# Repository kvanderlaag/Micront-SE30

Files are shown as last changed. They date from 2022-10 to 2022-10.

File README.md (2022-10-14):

# Micron't SE30 Beigescale Adapter
 
Micron XCEED CRT yoke board for internal greyscale on the Macintosh SE/30

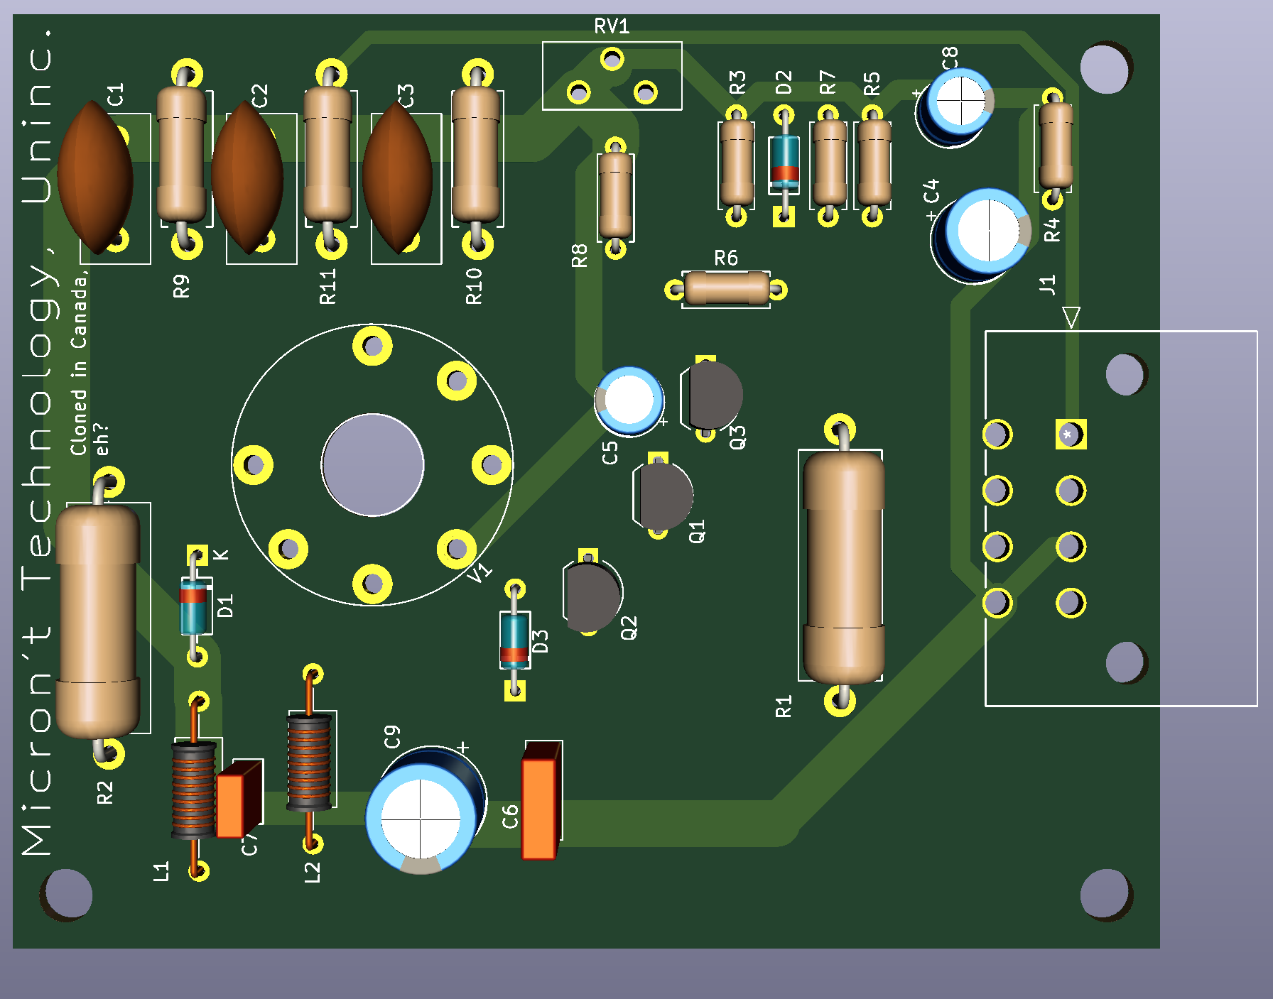
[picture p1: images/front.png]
Board front rendering

 
If you've miraculously stumbled across one (or two) of the assorted Micron SE/30 PDS video cards which have the connector for internal greyscale output, the piece you may be missing is the board which slaps onto the back of the CRT to let it run greyscale rather than black and white. (Also the associated adapter harness.)
 
As far as I know, these have been cloned many times, and sold by various parties. All of these clones are largely derived from [Gamba's original work to this end](http://web.archive.org/web/20010626004329/http://www.accesscom.com/~gamba/microngray.html), which is no longer actively available, but by the mercy of the [internet gods](https://www.archive.org) still archived. This board doesn't provide anything that the others don't -- it's also just a straight clone, though the routing and component placement is a little more closely derived from [D.S. Larsen's photos of the original Micron board.](http://web.archive.org/web/20010626004329/http://www.eskimo.com/~dslarsen/micron/)
 
The two important things about this design are:
1. That it was created on 14-10-2022, using footprints for parts that are actively available at this time, and
2. _That it actually fuckin' exists on GitHub, with an open license._ 
 
Take it, build it, fix it, improve it, use it to make a death ray; I don't care, just _actually do something with it_, because finding someone who will actually sell you one of these today is _annoyingly difficult_.
 
## Known Issues

There is currently one _massive_ caveat: I haven't actually built one of these yet. Everything appears to be lined up to the original board fairly accurately, and I'm confident in the routing relative to the original board and the schematic, but the one thing that concerns me is the footprint for the tube socket. The footprint was created with [this 7-pin miniature (B7G) tube socket, P/N B7G-PCB](http://www.pacifictv.ca/socket.htm) in mind, since the dimensions are provided, but I've also ordered a couple of tube sockets from Aliexpress; if those don't quite fit, I'll create a second version of the board with an updated footprint, just so that there's options for tube socket sourcing, since that seems like it could be a pain in the ass.

Also, obviously, since I haven't built it yet, there's no guarantee it won't blow up your SE/30, or your video card. Since both of these are quite expensive, maybe double check it against Gamba's (known-working) source material before you go build it. I'm not infallible -- in fact, I'm not even that smart -- but I'm also not your dad, so do what you want.

I still need to create a KiCAD schematic of the adapter harness, too.

## Bill of Materials

If you want to actually build this, you probably need some parts to do so. These are the parts the board was designed for; other parts with similar size, lead spacing, and characteristics will probably work fine.

| Quantity | Reference | Part Number | Description | Link | Alternate |
| --- | --- | --- | --- | --- | --- |
| 3 | C1,2,3 | CK45-E3AD103ZYVNA | Capacitor, ceramic disc, 0.01uF 1KVDC | https://www.mouser.ca/ProductDetail/810-CK45-E3AD103ZYVN | |
| 1 | C4 | ESS106M050AE2AA | Capacitor, electrolytic, 10uF, 50VDC, 105°C | https://www.mouser.ca/ProductDetail/80-ESS106M050AE2AA | |
| 1 | C5 | UVZ1A470MDD | Capacitor, electrolytic, 47uF, 10VDC, 105°C | https://www.mouser.ca/ProductDetail/647-UVZ1A470MDD | |
| 1 | C6 | R82EC3100DQ70J | Capacitor, film, 0.1uF, 100VDC | https://www.mouser.ca/ProductDetail/80-R82EC3100DQ70J | |
| 1 | C7 | K104Z15Y5VE5TL2 | Capacitor, multi-layered ceramic, 0.1uF, 25VDC | https://www.mouser.ca/ProductDetail/594-K104Z15Y5VE5TL2 | |
| 1 | C8 | UVZ1C101MDD | Capacitor, electrolytic, 100uF, 16VDC, 105°C | https://www.mouser.ca/ProductDetail/647-UVZ1C101MDD | |
| 1 | C9 | UPW1J101MPD6 | Capacitor, electrolytic, 100uF, 63VDC, 105°C | https://www.mouser.ca/ProductDetail/647-UPW1J101MPD6 | |
| 3 | D1,2,3 | 1N914BTR | Diode, 1N914A | https://www.mouser.ca/ProductDetail/512-1N914BTR | |
| 1 | J1 | 39-29-1088 | Connector, 8 pin, right-angle; Molex 5569 series | https://www.mouser.ca/ProductDetail/538-39-29-1088 | |
| 2 | L1,2 | 78F270J-RC | Inductor, 27 uH 5% | https://www.mouser.ca/ProductDetail/542-78F270-RC | |
| 2 | Q1,2 | 2N5550TFR | Transistor, NPN | https://www.mouser.ca/ProductDetail/512-2N5550TFR | |
| 1 | Q3 | PN2222ABU | Transistor, NPN | https://www.mouser.ca/ProductDetail/512-PN2222ABU | |
| 2 | R1,2 | CFR200JT-73-1K | Resistor, 1.0K ohms, 2W 5% | https://www.mouser.ca/ProductDetail/YAGEO/CFR200JT-73-1K | |
| 1 | R3 | CFR-25JB-52-75R | Resistor, 75 ohms, 1/4W 5% | https://www.mouser.ca/ProductDetail/YAGEO/CFR-25JB-52-75R  | |
| 1 | R4 | CFR-25JR-52-300R | Resistor,  300 ohms, 1/4W 5% | https://www.mouser.ca/ProductDetail/YAGEO/CFR-25JR-52-300R | |
| 1 | R5 | CFR-25JT-52-56R | Resistor, 56 ohms, 1/4W 5% | https://www.mouser.ca/ProductDetail/YAGEO/CFR-25JT-52-56R  | |
| 1 | R6 | CFR-25JT-52-200R | Resistor,  200 ohms, 1/4W 5% | https://www.mouser.ca/ProductDetail/YAGEO/CFR-25JT-52-200R | |
| 1 | R7 | CFR-25JT-52-12K | Resistor,  12K ohms, 1/4W 5% | https://www.mouser.ca/ProductDetail/YAGEO/CFR-25JT-52-12K  | |
| 1 | R8 | CFR-25JB-52-1K5 | Resistor, 1.5K ohms, 1/4W 5% | https://www.mouser.ca/ProductDetail/YAGEO/CFR-25JB-52-1K5  | |
| 3 | R9,10,11  | CFR50SJT-52-100K | Resistor, 100K ohms, 1/2W 5% | https://www.mouser.ca/ProductDetail/YAGEO/CFR50SJT-52-100K | |
| 1 | RV1 | PT10LH01-201A2020-S | Resistor, variable, 200 ohms | https://www.mouser.ca/ProductDetail/531-PT10H-200-S | |
| 1 | V1 | APCO EIA-1210 / B7G-PCB | Socket, CRT, 7 pin miniature, PC mount | http://www.pacifictv.ca/socket.htm | https://www.aliexpress.com/item/1549957333.html |

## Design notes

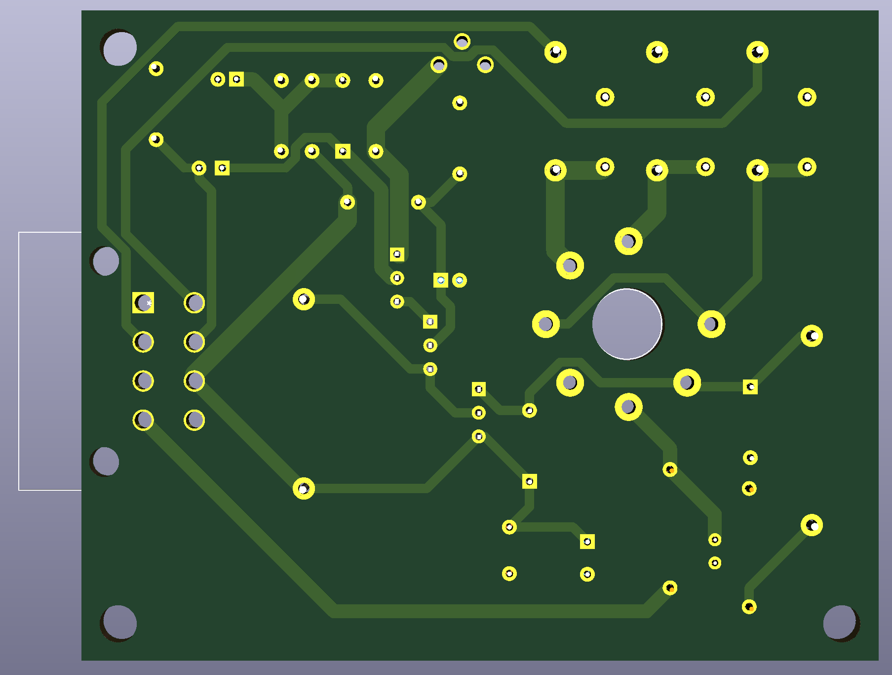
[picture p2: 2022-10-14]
images/back.png

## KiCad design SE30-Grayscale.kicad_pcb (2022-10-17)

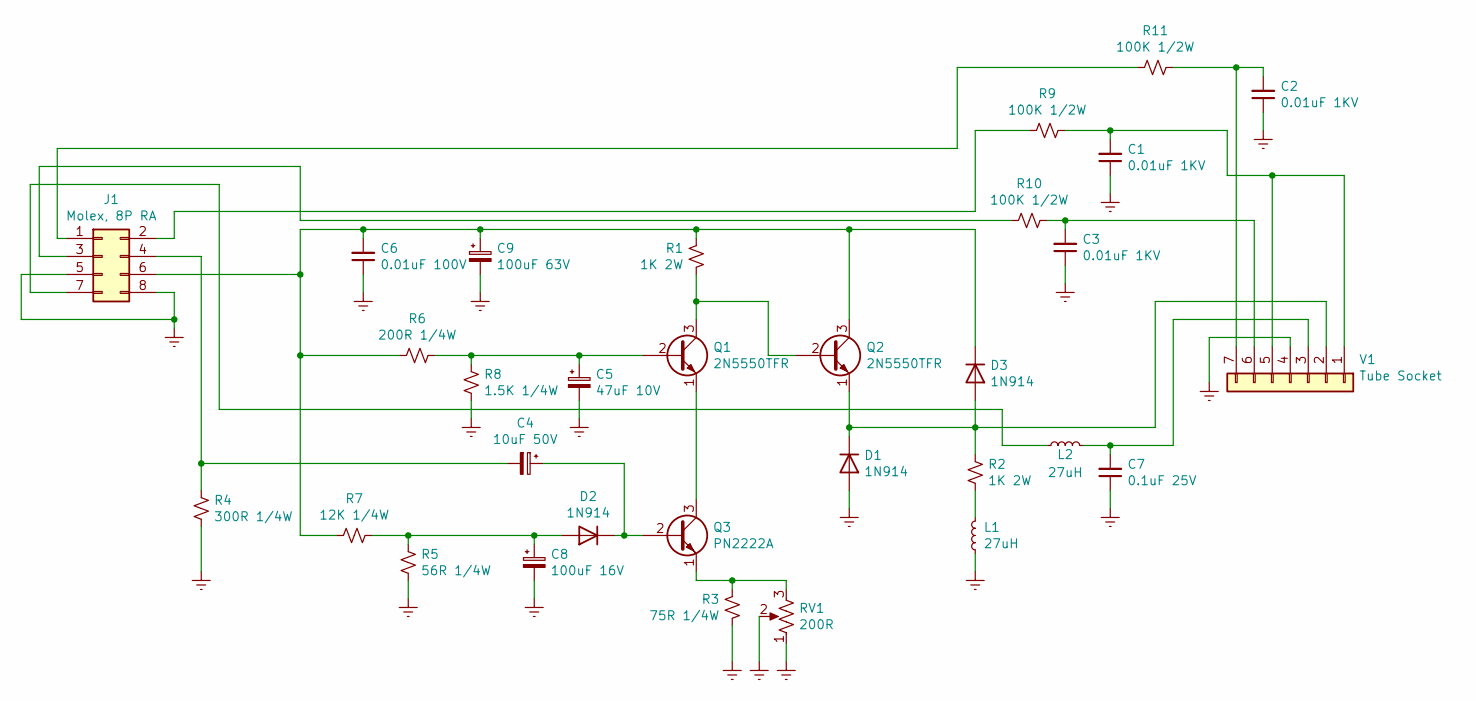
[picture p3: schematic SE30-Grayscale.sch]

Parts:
C1, C2, C3: 0.01uF 1KV; C_Disc_D11.0mm_W5.0mm_P7.50mm
C4: 10uF 50V; CP_Radial_D6.3mm_P2.50mm
C5: 47uF 10V; CP_Radial_D5.0mm_P2.00mm
C6: 0.01uF 100V; C_Rect_L7.2mm_W2.5mm_P5.00mm_FKS2_FKP2_MKS2_MKP2
C7: 0.1uF 25V; C_Rect_L4.6mm_W2.0mm_P2.50mm_MKS02_FKP02
C8: 100uF 16V; CP_Radial_D5.0mm_P2.00mm
C9: 100uF 63V; CP_Radial_D8.0mm_P3.50mm
D1, D2, D3: 1N914; D_DO-35_SOD27_P7.62mm_Horizontal
J1: Molex, 8P RA; Molex
L1, L2: 27uH; L_Axial_L7.0mm_D3.3mm_P12.70mm_Horizontal_Fastron_MICC
Q1, Q2: 2N5550TFR; TO-92_Inline_Wide
Q3: PN2222A; TO-92_Inline_Wide
R1, R2: 1K 2W; R_Axial_DIN0617_L17.0mm_D6.0mm_P20.32mm_Horizontal
R3: 75R 1/4W; R_Axial_DIN0207_L6.3mm_D2.5mm_P7.62mm_Horizontal
R4: 300R 1/4W; R_Axial_DIN0207_L6.3mm_D2.5mm_P7.62mm_Horizontal
R5: 56R 1/4W; R_Axial_DIN0207_L6.3mm_D2.5mm_P7.62mm_Horizontal
R6: 200R 1/4W; R_Axial_DIN0207_L6.3mm_D2.5mm_P7.62mm_Horizontal
R7: 12K 1/4W; R_Axial_DIN0207_L6.3mm_D2.5mm_P7.62mm_Horizontal
R8: 1.5K 1/4W; R_Axial_DIN0207_L6.3mm_D2.5mm_P7.62mm_Horizontal
R9, R10, R11: 100K 1/2W; R_Axial_DIN0411_L9.9mm_D3.6mm_P12.70mm_Horizontal
RV1: 200R; Trimmer_Res_Amphenol
V1: Tube Socket; Tube-7pin-Mini

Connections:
Earth: C1.1, C2.1, C3.1, C5.2, C6.1, C7.1, C8.2, C9.2, D1.2 (A), J1.5, J1.8, L1.1, R3.1, R4.1, R5.2, R8.1, RV1.1, RV1.2, V1.4
unnamed: C1.2, R9.1, V1.1, V1.5
unnamed: C2.2, R11.1, V1.7
unnamed: C3.2, R10.1, V1.6
unnamed: C4.1, D2.1 (K), Q3.2 (B)
unnamed: C4.2, J1.4, R4.2
unnamed: C5.1, Q1.2 (B), R6.1, R8.2
unnamed: C6.2, C9.1, D3.1 (K), J1.6, Q2.3 (C), R1.2, R6.2, R7.1
unnamed: C7.2, L2.2, V1.3
unnamed: C8.1, D2.2 (A), R5.1, R7.2
unnamed: D1.1 (K), D3.2 (A), Q2.1 (E), R2.2, V1.2
unnamed: J1.1, R11.2
unnamed: J1.2, R9.2
unnamed: J1.3, R10.2
unnamed: J1.7, L2.1
unnamed: L1.2, R2.1
unnamed: Q1.1 (E), Q3.3 (C)
unnamed: Q1.3 (C), Q2.2 (B), R1.1
unnamed: Q3.1 (E), R3.2, RV1.3

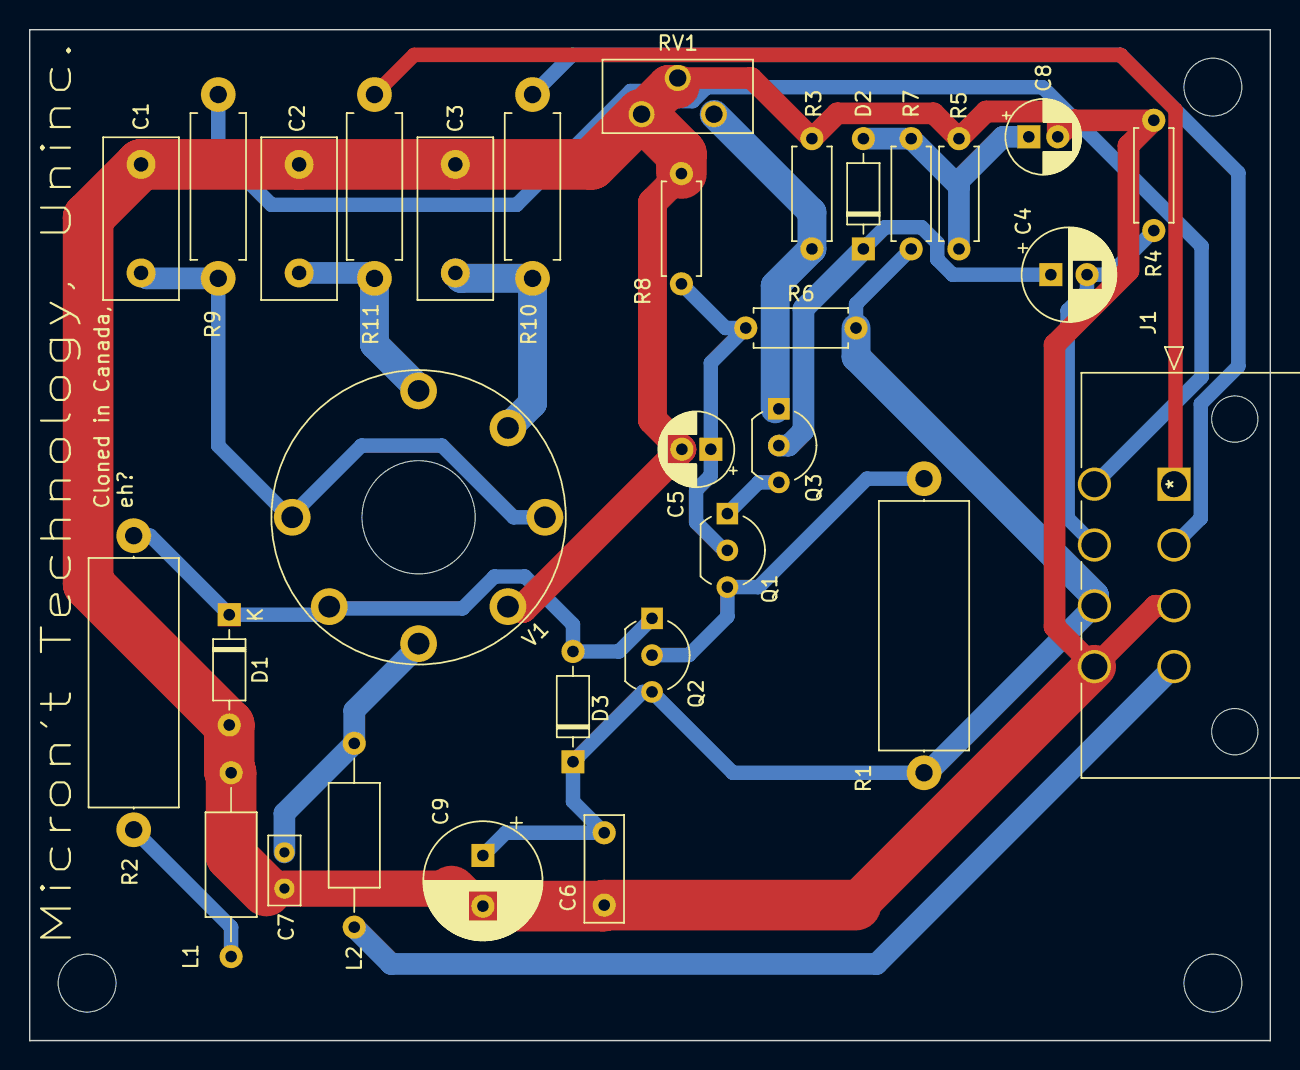
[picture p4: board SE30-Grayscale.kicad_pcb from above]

Board: 2 copper layers, 85.7 x 69.8 mm, 31 parts (0 on the bottom side), 19 nets.

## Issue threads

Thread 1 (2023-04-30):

Wrong resistance values for R5, R6

tvjctr, 2023-04-30:
I was cross referencing your BOM to create an order to finish a grayscale neck board, when I noticed resistor R5 and R6 are incorrect.

R5 should be a 560 ohms resistor, and R6 should be a 20K ohms resistor.

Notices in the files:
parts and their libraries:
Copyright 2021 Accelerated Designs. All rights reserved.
